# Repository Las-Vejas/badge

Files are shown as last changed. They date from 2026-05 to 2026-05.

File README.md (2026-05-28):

<h1 align="center">
  <br>
  <a href="https://vejas.zip">
<p align="center">
  
</p>  </a>
  <br>
  <sub>VejasBadge</sub>
  <br>
</h1>

<div align="center">
  
  
  
</div>

<h4 align="center">An E-ink badge powered by the RP2040 MCU.</h4>

<br>

## Overview

VejasBadge is a compact wearable badge built around the Raspberry Pi **RP2040** microcontroller. It features an **E-ink display**, **NFC** via the ST25DV04K, and is powered over **USB-C** with battery charging support. 

It will be used to display info like my name, website and a photo of some sort. If the NFC coil works, I will add functionality, to choose the info transmitted by the NFC tag so you could share multiple website links. I would also like to use it as an ebook reader, but there may not be enough storage for that.

## Features

| Feature | Details |
|---|---|
| MCU | RP2040 @ 133MHz, LQFN-56 |
| Display | E-ink panel via 24-pin FPC connector (4-wire SPI) |
| NFC | ST25DV04K (ISO 15693 / I²C, 4Kbit) |
| Flash | ZD25WQ32CEIGR 32Mbit SPI Flash |
| RTC / Clock | ABM8-272-T3 crystal oscillator |
| Power | USB-C input, NCP1117ST33T3G 3.3V LDO|
| USB Protection | USBLC6-2SC6 ESD clamp |
| Buttons | 5× tactile switches (SKRKAEE020) |
| LEDs | 2× white status LEDs (0402) |

## Software

Firmware will be written in C++ using PlatformIO.

## Images
<p align="center">
  
</p>

## Bill of Materials

### LCSC Components

| Part | Mfr. | Qty | Unit Price | Ext. Price | LCSC# |
|---|---|-----|---|---|---|
| RP2040 | Raspberry Pi | 5 | $0.95 | $4.74 | [C2040](https://www.lcsc.com/product-detail/C2040.html) |
| ZD25WQ32CEIGR (32Mbit Flash) | Zetta | 5 | $0.57 | $2.86 | [C5258281](https://www.lcsc.com/product-detail/C5258281.html) |
| ST25DV04K-JFR6D3 (NFC) | ST | 5 | $0.86 | $4.30 | [C2654815](https://www.lcsc.com/product-detail/C2654815.html) |
| ABM8-272-T3 (Crystal) | ABRACON | 5 | $0.29 | $1.47 | [C20625731](https://www.lcsc.com/product-detail/C20625731.html) |
| NCP1117ST33T3G (LDO 3.3V) | onsemi | 5 | $0.24 | $1.18 | [C26537](https://www.lcsc.com/product-detail/C26537.html) |
| FPC-05F-24PH20 (24P FPC Connector) | XUNPU | 5 | $0.10 | $0.48 | [C2856805](https://www.lcsc.com/product-detail/C2856805.html) |
| USBLC6-2SC6 (ESD Protection) | HXY MOSFET | 5 | $0.03 | $0.16 | [C5261088](https://www.lcsc.com/product-detail/C5261088.html) |
| SI1308EDL (N-MOSFET) | TECH PUBLIC | 5 | $0.08 | $0.42 | [C7603347](https://www.lcsc.com/product-detail/C7603347.html) |
| MBR0530 (Schottky Diode) | Shikues | 50 | $0.02 | $1.00 | [C475718](https://www.lcsc.com/product-detail/C475718.html) |
| LB2012T680M (68µH Inductor) | Taiyo Yuden | 10 | $0.05 | $0.47 | [C223256](https://www.lcsc.com/product-detail/C223256.html) |
| YLED0402W (White LED) | YONGYUTAI | 50 | $0.015 | $0.77 | [C28310435](https://www.lcsc.com/product-detail/C28310435.html) |
| SKRKAEE020 (Tactile Switch) | Alps Alpine | 35 | $0.13 | $4.67 | [C115357](https://www.lcsc.com/product-detail/C115357.html) |
| USB-C Receptacle 16P | SHOU HAN | 20 | $0.07 | $1.48 | [C2765186](https://www.lcsc.com/product-detail/C2765186.html) |
| Cap 100nF 0402 | YAGEO | 100 | $0.001 | $0.13 | [C60474](https://www.lcsc.com/product-detail/C60474.html) |
| Cap 15pF 0402 NP0 | YAGEO | 100 | $0.001 | $0.13 | [C106997](https://www.lcsc.com/product-detail/C106997.html) |
| Cap 33pF 0402 NP0 | YAGEO | 100 | $0.001 | $0.13 | [C107005](https://www.lcsc.com/product-detail/C107005.html) |
| Cap 1µF 10V 0402 | Samsung EM | 100 | $0.003 | $0.30 | [C14445](https://www.lcsc.com/product-detail/C14445.html) |
| Cap 4.7µF 10V 0402 | Samsung EM | 50 | $0.008 | $0.39 | [C368809](https://www.lcsc.com/product-detail/C368809.html) |
| Cap 10µF 10V 0402 | Samsung EM | 20 | $0.012 | $0.23 | [C315248](https://www.lcsc.com/product-detail/C315248.html) |
| Res 3Ω 0402 | YAGEO | 100 | $0.002 | $0.20 | [C227064](https://www.lcsc.com/product-detail/C227064.html) |
| Res 27Ω 0402 | YAGEO | 100 | $0.001 | $0.09 | [C138021](https://www.lcsc.com/product-detail/C138021.html) |
| Res 1kΩ 0402 | YAGEO | 100 | $0.001 | $0.09 | [C106235](https://www.lcsc.com/product-detail/C106235.html) |
| Res 5.1kΩ 0402 | YAGEO | 100 | $0.001 | $0.09 | [C105872](https://www.lcsc.com/product-detail/C105872.html) |
| Res 10kΩ 0402 | YAGEO | 100 | $0.001 | $0.09 | [C60490](https://www.lcsc.com/product-detail/C60490.html) |

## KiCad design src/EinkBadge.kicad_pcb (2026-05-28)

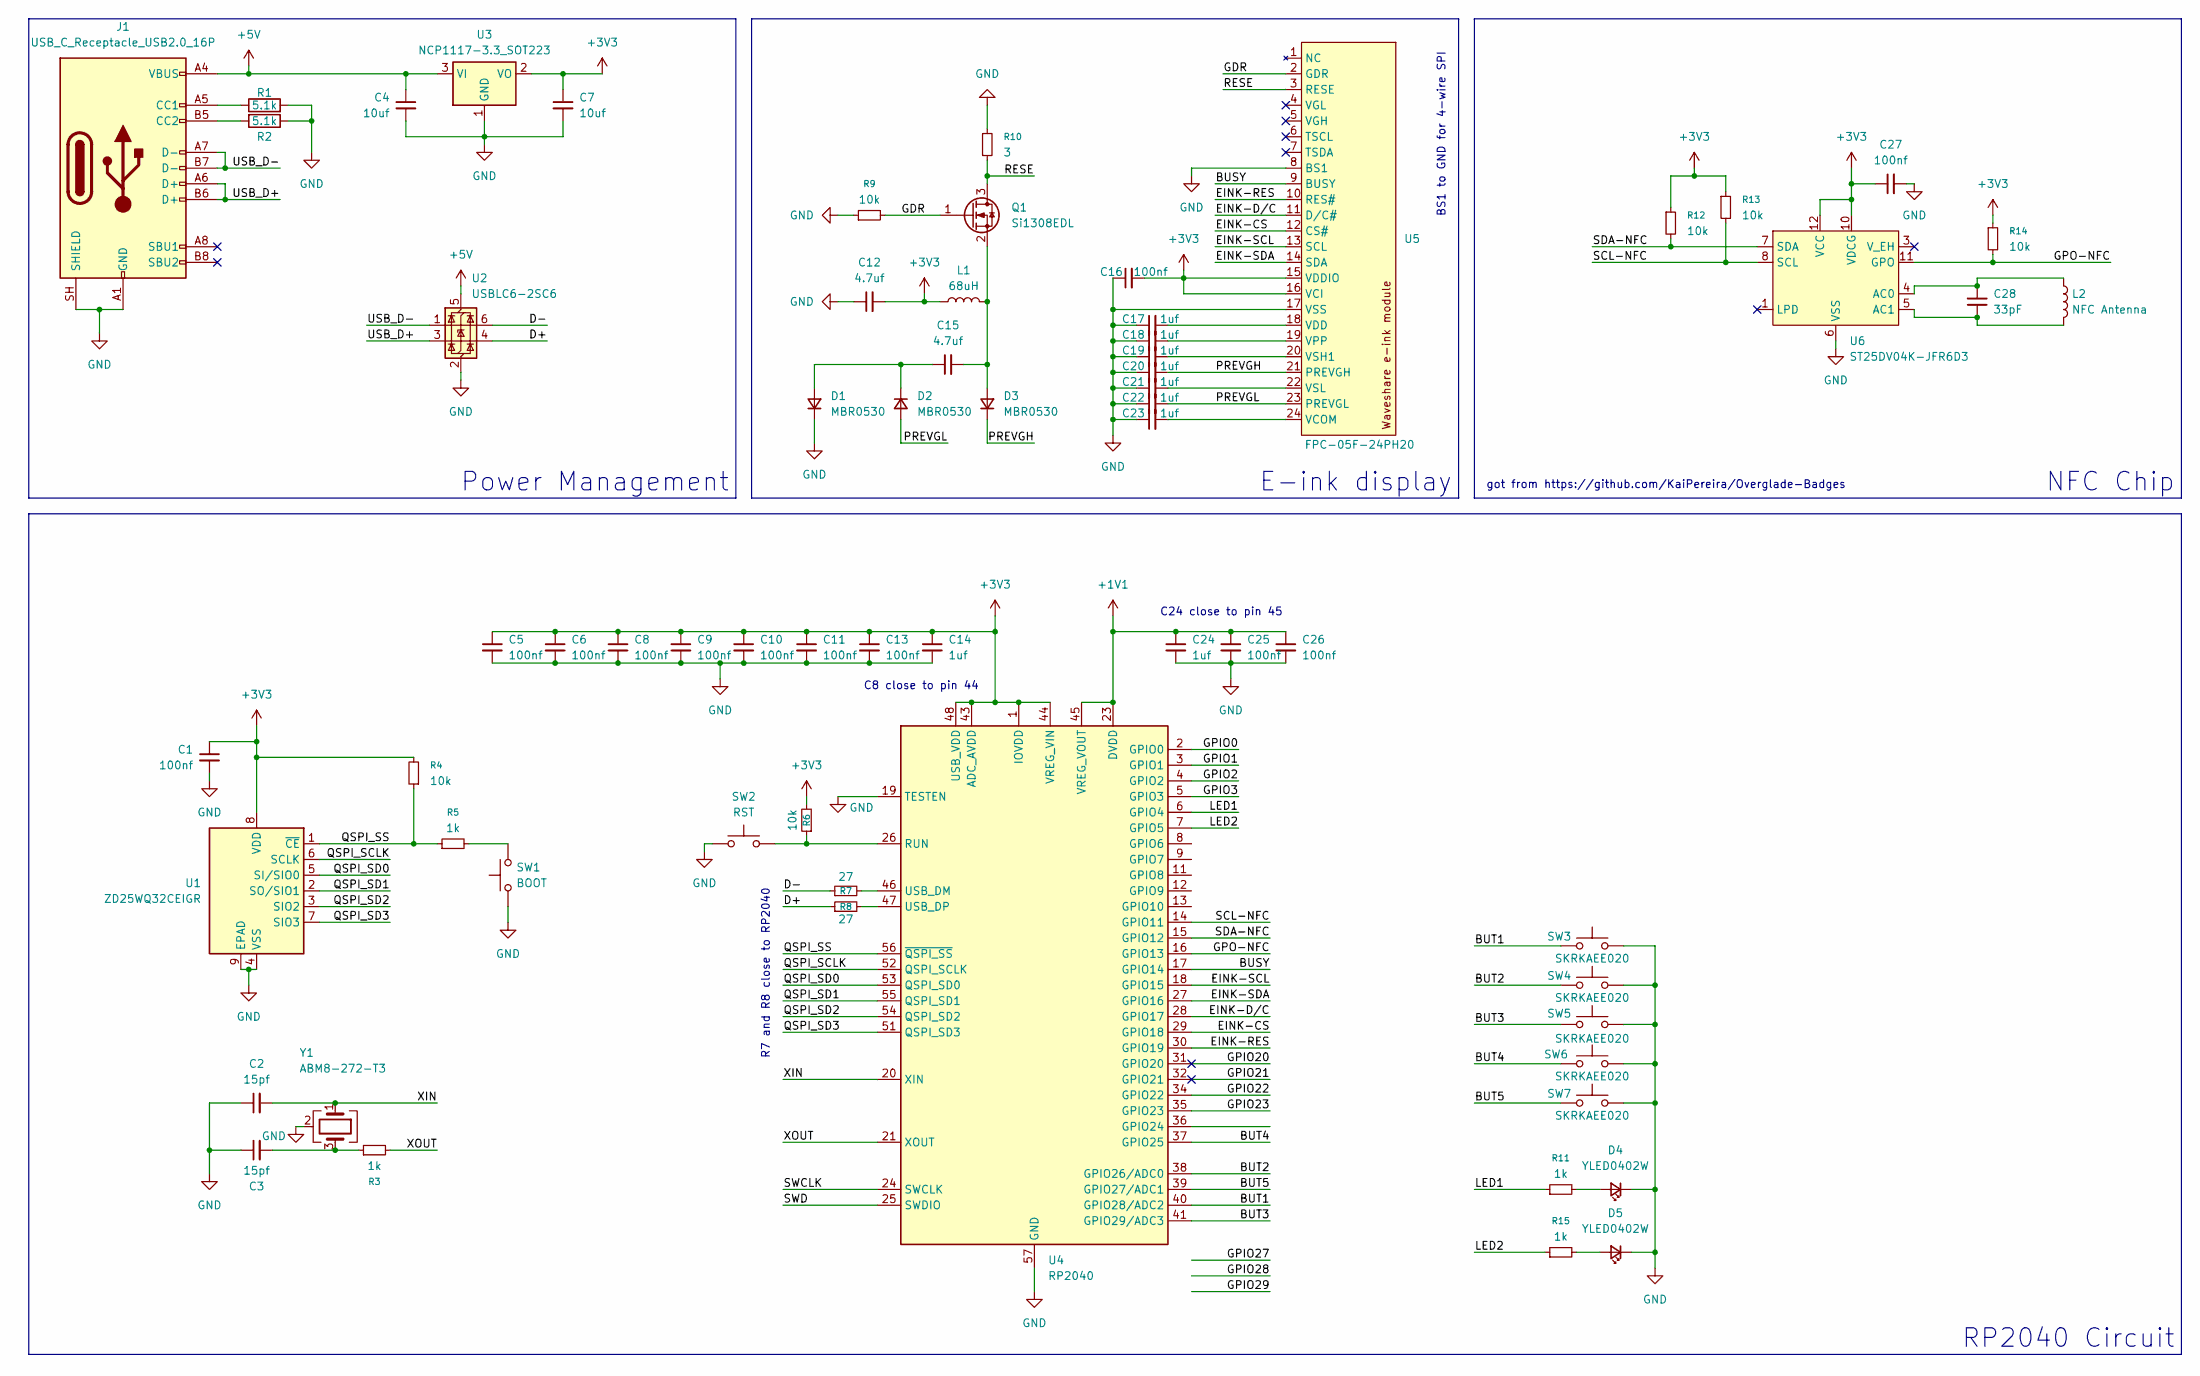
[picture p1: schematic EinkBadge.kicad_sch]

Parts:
C1, C5, C6, C8, C9, C10, C11, C13, C16, C25, C26, C27: 100nf; C_0402_1005Metric
C2, C3: 15pf; C_0402_1005Metric
C4, C7: 10uf; C_0402_1005Metric
C12, C15: 4.7uf; C_0402_1005Metric
C14, C17, C18, C19, C20, C21, C22, C23, C24: 1uf; C_0402_1005Metric
C28: 33pF; C_0402_1005Metric
D1, D2, D3: MBR0530; D_SOD-123
D4, D5: YLED0402W; LED_0402_1005Metric
J1: USB_C_Receptacle_USB2.0_16P; USB_C_Receptacle_GCT_USB4105-xx-A_16P_TopMnt_Horizontal
L1: 68uH; L_0805_2012Metric
L2: NFC Antenna; eink_badge_nfc5
Q1: Si1308EDL; SOT-323_SC-70
R1, R2: 5.1k; R_0402_1005Metric
R3, R5, R11, R15: 1k; R_0402_1005Metric
R4, R6, R9, R12, R13, R14: 10k; R_0402_1005Metric
R7, R8: 27; R_0402_1005Metric
R10: 3; R_0402_1005Metric
SW1: BOOT; SW_Push_SPST_NO_Alps_SKRK
SW2: RST; SW_Push_SPST_NO_Alps_SKRK
SW3, SW4, SW5, SW6, SW7: SKRKAEE020; SW_Push_SPST_NO_Alps_SKRK
U1: ZD25WQ32CEIGR; Winbond_USON-8-1EP_3x2mm_P0.5mm_EP0.2x1.6mm
U2: USBLC6-2SC6; SOT-23-6
U3: NCP1117-3.3_SOT223; SOT-223-3_TabPin2
U4: RP2040; QFN-56-1EP_7x7mm_P0.4mm_EP3.2x3.2mm
U5: FPC-05F-24PH20; TE_2-1734839-4_1x24-1MP_P0.5mm_Horizontal
U6: ST25DV04K-JFR6D3; ST_UFDFPN-12-1EP_3x3mm_P0.5mm_EP1.4x2.55mm
Y1: ABM8-272-T3; Crystal_SMD_3225-4Pin_3.2x2.5mm

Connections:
+1V1: C24.1, C25.1, C26.1, U4.23 (DVDD), U4.45 (VREG_VOUT), U4.50 (DVDD)
+3V3: C1.1, C5.1, C6.1, C7.1, C8.1, C9.1, C10.1, C11.1, C12.2, C13.1, C14.1, C16.2, C27.1, L1.1, R4.2, R6.2, R12.1, R13.1, R14.1, U1.8 (VDD), U3.2 (VO), U4.1 (IOVDD), U4.10 (IOVDD), U4.22 (IOVDD), U4.33 (IOVDD), U4.42 (IOVDD), U4.43 (ADC_AVDD), U4.44 (VREG_VIN), U4.48 (USB_VDD), U4.49 (IOVDD), U5.15 (VDDIO), U5.16 (VCI), U6.10 (VDCG), U6.12 (VCC)
+5V: C4.1, J1.A4 (VBUS), J1.A9 (VBUS), J1.B4 (VBUS), J1.B9 (VBUS), U2.5 (VBUS), U3.3 (VI)
/BUSY: U4.17 (GPIO14), U5.9 (BUSY)
/BUT1: SW3.1, U4.40 (GPIO28/ADC2)
/BUT2: SW4.1, U4.38 (GPIO26/ADC0)
/BUT3: SW5.1, U4.41 (GPIO29/ADC3)
/BUT4: SW6.1, U4.37 (GPIO25)
/BUT5: SW7.1, U4.39 (GPIO27/ADC1)
/D+: R8.1, U2.4 (I/O2)
/D-: R7.1, U2.6 (I/O1)
/EINK-CS: U4.29 (GPIO18), U5.12 (CS#)
/EINK-D/C: U4.28 (GPIO17), U5.11 (D/C#)
/EINK-RES: U4.30 (GPIO19), U5.10 (RES#)
/EINK-SCL: U4.18 (GPIO15), U5.13 (SCL)
/EINK-SDA: U4.27 (GPIO16), U5.14 (SDA)
/GDR: Q1.1 (G), R9.2, U5.2 (GDR)
/GPIO0: U4.2 (GPIO0)
/GPIO1: U4.3 (GPIO1)
/GPIO2: U4.4 (GPIO2)
/GPIO3: U4.5 (GPIO3)
/GPIO20: U4.31 (GPIO20)
/GPIO21: U4.32 (GPIO21)
/GPIO22: U4.34 (GPIO22)
/GPIO23: U4.35 (GPIO23)
/GPO-NFC: R14.2, U4.16 (GPIO13), U6.11 (GPO)
/LED1: R11.1, U4.6 (GPIO4)
/LED2: R15.1, U4.7 (GPIO5)
/PREVGH: C20.2, D3.1 (K), U5.21 (PREVGH)
/PREVGL: C22.2, D2.2 (A), U5.23 (PREVGL)
/QSPI_SCLK: U1.6 (SCLK), U4.52 (QSPI_SCLK)
/QSPI_SD0: U1.5 (SI/SIO0), U4.53 (QSPI_SD0)
/QSPI_SD1: U1.2 (SO/SIO1), U4.55 (QSPI_SD1)
/QSPI_SD2: U1.3 (SIO2), U4.54 (QSPI_SD2)
/QSPI_SD3: U1.7 (SIO3), U4.51 (QSPI_SD3)
/QSPI_SS: R4.1, R5.1, U1.1 (~CE), U4.56 (~QSPI_SS)
/RESE: Q1.3 (D), R10.2, U5.3 (RESE)
/SCL-NFC: R13.2, U4.14 (GPIO11), U6.8 (SCL)
/SDA-NFC: R12.2, U4.15 (GPIO12), U6.7 (SDA)
/SWCLK: U4.24 (SWCLK)
/SWD: U4.25 (SWDIO)
/USB_D+: J1.A6 (D+), J1.B6 (D+), U2.3 (I/O2)
/USB_D-: J1.A7 (D-), J1.B7 (D-), U2.1 (I/O1)
/XIN: C2.2, U4.20 (XIN), Y1.1
/XOUT: R3.2, U4.21 (XOUT)
GND: C1.2, C2.1, C3.1, C4.2, C5.2, C6.2, C7.2, C8.2, C9.2, C10.2, C11.2, C12.1, C13.2, C14.2, C16.1, C17.1, C18.1, C19.1, C20.1, C21.1, C22.1, C23.1, C24.2, C25.2, C26.2, C27.2, D1.1 (K), D4.1 (K), D5.1 (K), J1.A1 (GND), J1.A12 (GND), J1.B1 (GND), J1.B12 (GND), J1.SH (SHIELD), R1.2, R2.1, R9.1, R10.1, SW1.1, SW2.1, SW3.2, SW4.2, SW5.2, SW6.2, SW7.2, U1.4 (VSS), U1.9 (EPAD), U2.2 (GND), U3.1 (GND), U4.19 (TESTEN), U4.57 (GND), U5.8 (BS1), U5.17 (VSS), U6.6 (VSS), Y1.2 (G), Y1.4 (G)
unnamed: C3.2, R3.1, Y1.3
unnamed: C15.1, D1.2 (A), D2.1 (K)
unnamed: C15.2, D3.2 (A), L1.2, Q1.2 (S)
unnamed: D4.2 (A), R11.2
unnamed: D5.2 (A), R15.2
unnamed: J1.A5 (CC1), R1.1
unnamed: J1.B5 (CC2), R2.2
unnamed: R5.2, SW1.2
unnamed: R6.1, SW2.2, U4.26 (RUN)
unnamed: R7.2, U4.46 (USB_DM)
unnamed: R8.2, U4.47 (USB_DP)
unnamed: C23.2, U5.24 (VCOM)
unnamed: C17.2, U5.18 (VDD)
unnamed: C18.2, U5.19 (VPP)
unnamed: C19.2, U5.20 (VSH1)
unnamed: C21.2, U5.22 (VSL)
unnamed: C28.2, L2.1, U6.4 (AC0)
unnamed: C28.1, L2.2, U6.5 (AC1)

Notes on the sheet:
R7 and R8 close to RP2040
got from https://github.com/KaiPereira/Overglade-Badges
C24 close to pin 45
C8 close to pin 44
BS1 to GND for 4-wire SPI
RP2040 Circuit
Power Management
E-ink display
NFC Chip

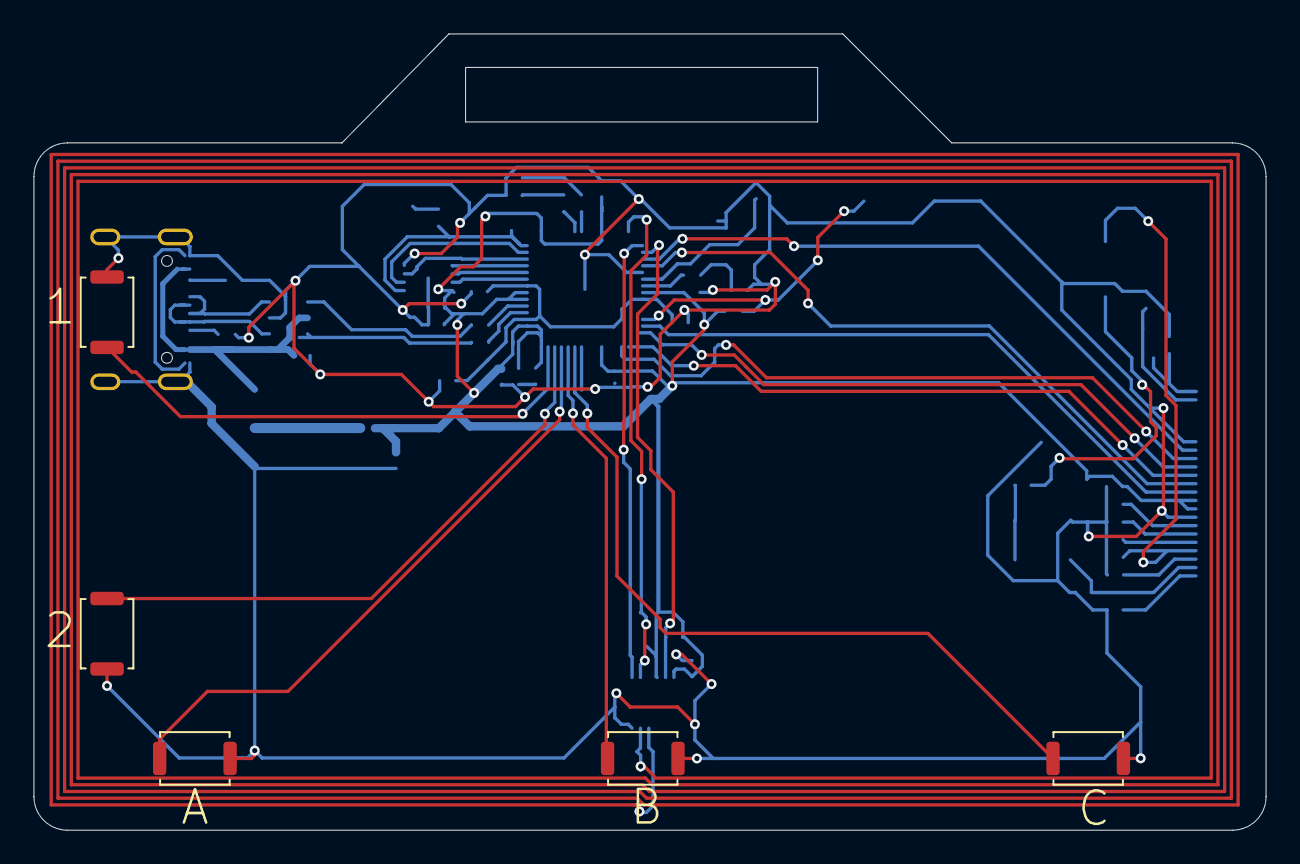
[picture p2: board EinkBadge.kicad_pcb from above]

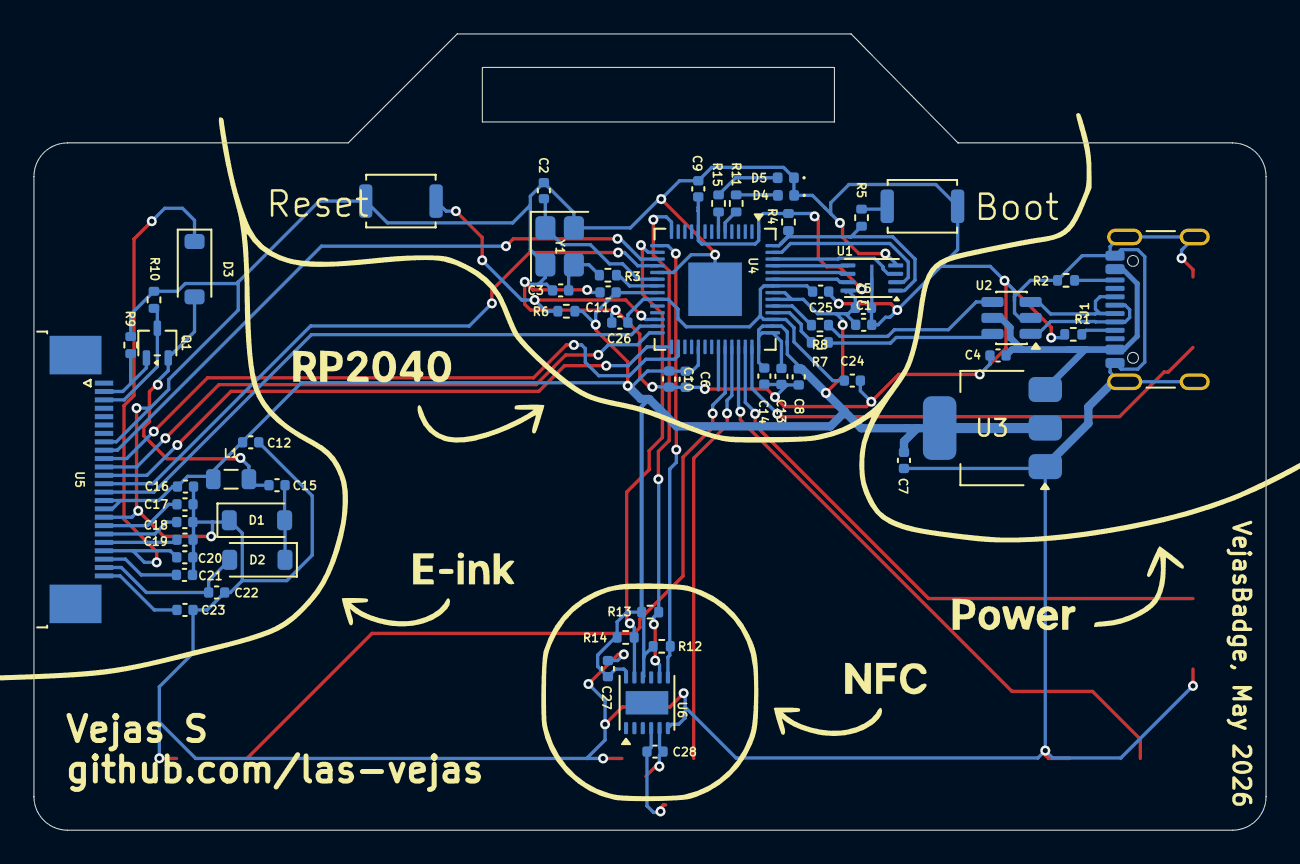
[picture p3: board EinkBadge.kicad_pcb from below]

Board: 2 copper layers, 73.5 x 47.5 mm, 66 parts (60 on the bottom side), 54 nets.
